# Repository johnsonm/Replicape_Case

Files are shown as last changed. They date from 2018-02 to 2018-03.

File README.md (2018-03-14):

Obsolete
========

This remix + design was abandoned and replaced by my from-scratch
(Replicase)[https://github.com/johnsonm/Replicase] design, done
entirely in OpenSCAD.  I have no intention to do any further work
on this remix of Replicape Case.  You are welcome to use it, but
I have no plans to pay attention to PRs for this repository.

OpenSCAD remixes of Replicape case, changing ventilation.

Originally:

https://www.thingiverse.com/thing:2610261
Replicape Case by andrewmirskytech is licensed under the Creative Commons - Attribution license.
http://creativecommons.org/licenses/by/3.0/

# Summary

A case for the Replicape with vents for two 30mm fans.

Use #4-40 x 3/4" countersunk (or M3 x 20) for top case.
Use #4-40 x 1/4" or M3 x 6mm for mounting the beaglebone.

There is now a bottom case version with mounting holes.

# How I Designed This

## OnShape

https://cad.onshape.com/documents/5606d2f84fb4a684de3a789f/w/2d6b5478c237fdbb73e455b0/e/285e4ce3e6625645cad0e7fc

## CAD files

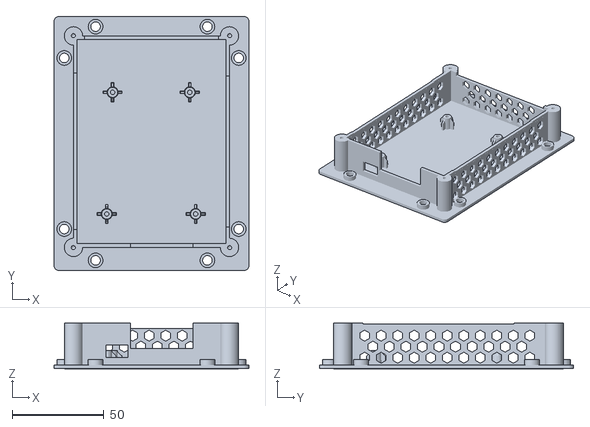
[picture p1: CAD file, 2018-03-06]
extra_ventilation_bottom_with_mounts.stl
106.1 x 138.4 x 24.8

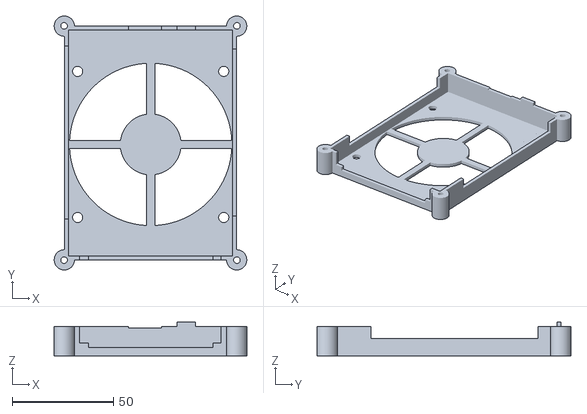
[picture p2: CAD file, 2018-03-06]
80mm-fan-top.stl
95.0 x 125.2 x 16.7

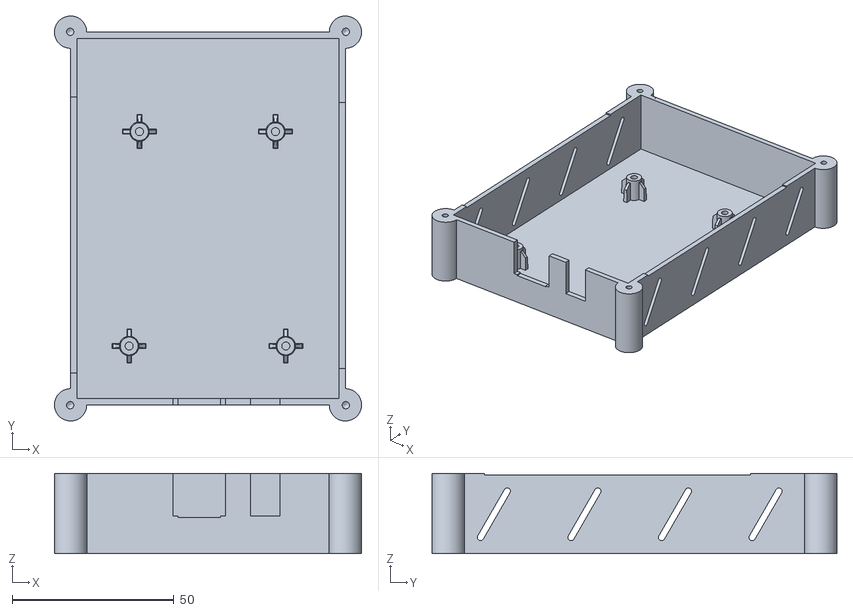
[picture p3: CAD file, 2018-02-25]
replicape_case_-_bottom.stl
95.0 x 125.2 x 24.8

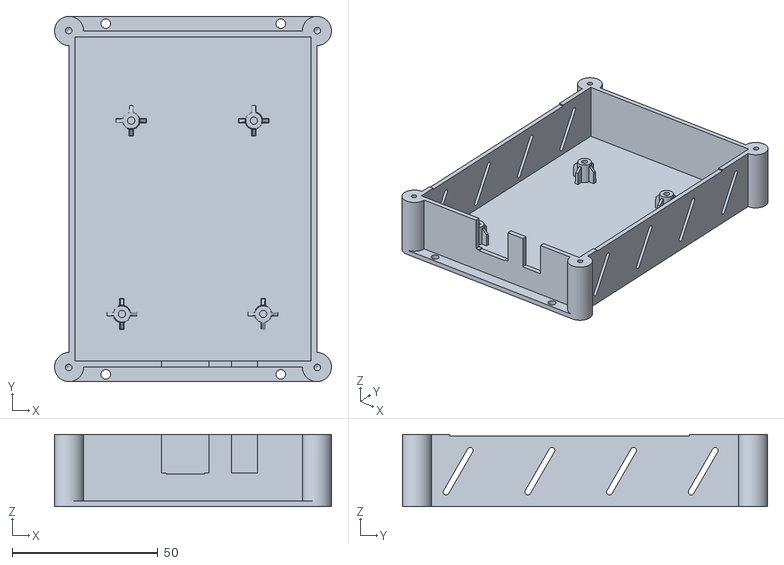
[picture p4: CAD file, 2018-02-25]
replicape_case_-_bottom_with_mounts.stl
95.0 x 125.2 x 24.8

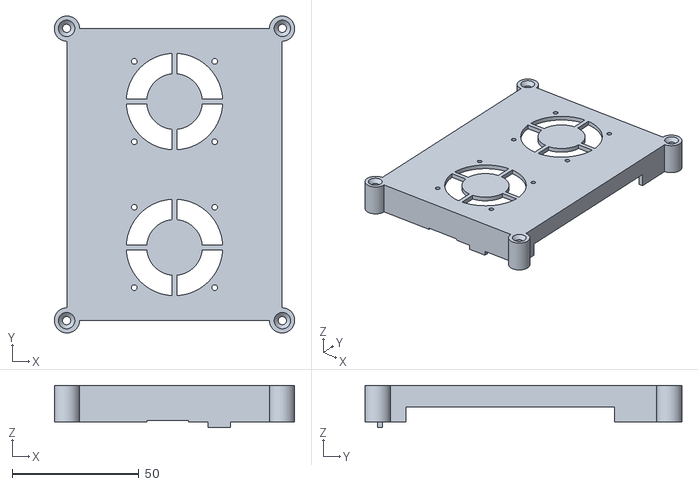
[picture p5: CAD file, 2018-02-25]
replicape_case_-_top.stl
95.0 x 125.2 x 16.6

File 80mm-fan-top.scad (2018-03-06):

// remove grills for two smaller fans
// replace with one 80mm fan
// this should be more parameterized; numbers are approximate
face = 2.02;
$fn = 180;
screw_off = 36; // x/y offsets for mounting screw holes
screw_d = 5;    // hole diameter for mounting screws

difference() {
    union() {
        // turn upside down and align with 0 Z to print and model
        translate([0, 0, 18.86]) rotate([180, 0, 0])
            import("replicape_case_-_top.stl");
        // fill in the old fan grills
        translate([-30, -50, 0]) cube([60, 100, face]);
    }
    union() {
        // this difference is itself subtracted, so the
        // effect is essentially inverted
        difference() {
            union() {
                // fan area
                cylinder(d=80, h=face);
                // mounting screw holes
                translate([-screw_off, -screw_off, 0]) cylinder(d=screw_d, h=face);
                translate([screw_off, -screw_off, 0]) cylinder(d=screw_d, h=face);
                translate([-screw_off, screw_off, 0]) cylinder(d=screw_d, h=face);
                translate([screw_off, screw_off, 0]) cylinder(d=screw_d, h=face);
            }
            union() {
                // grill center and bars
                cylinder(d=30, h=face);
                translate([-40, -2, 0]) cube([80, 4, face]);
                translate([-2, -40, 0]) cube([4, 80, face]);
            }
        }
    }
}

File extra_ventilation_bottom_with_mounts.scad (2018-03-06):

// I wanted a case with more airflow than the original design
// and with cutouts to fit the beaglebone green
// The case is not quite centered; the numbers are approximate
// There are a lot of "magic numbers" here from experimenting
x_off_p = 40.37;
x_off_n = 40.56;
shell = 2.05;
y_off_n = 58.31;
y_off_p = 54.88;
hd = 3; // air holes
m_d = 5.2; // diameter of mounting holes in flange
flange = 10; // width of mounting flange

module side_fill(x_off) {
    translate([x_off, -(y_off_n-(2*shell)), 0])
        cube([shell, 2*(y_off_n-(2*shell)), 23]);
}
module hex_hole(x, y, z, r=0) {
    $fn = 6;
    translate([x, y, z]) rotate([0, 90, r]) cylinder(r=hd, h=shell);
}
module vents(x_off) {
    for (y=[-(y_off_n-4*hd):3*hd:(y_off_n-4*hd)]) {
        hex_hole(x_off, y, 2*hd);
        hex_hole(x_off, y, 6*hd);
    }
    for (y=[-(y_off_n-5.5*hd):3*hd:(y_off_n-5.5*hd)]) {
        hex_hole(x_off, y, 4*hd);
    }
}
module end_vents(y_off) {
    for (x=[-(x_off_p-4*hd):3*hd:(x_off_n-4*hd)]) {
        hex_hole(x, y_off_p, 2*hd, 90);
        hex_hole(x, y_off_p, 6*hd, 90);
    }
    for (x=[-(x_off_p-5.5*hd):3*hd:(x_off_n-5.5*hd)]) {
        hex_hole(x, y_off_p, 4*hd, 90);
    }
}
module end_power_cutout() {
    translate([-(x_off_n-(2*shell)), y_off_p, 22])
        cube([x_off_p+x_off_n-(4*shell), shell, 3]);
}
module bbg_slots() {
    // beaglebone green has wider USB instead of 5V barrel,
    // and just leave room for some manufacturing variance
    translate([-11.5, -y_off_n, 11]) cube([34, shell, 15]);
    // and USB mini under the board
    translate([-25, -y_off_n, 6]) cube([12, shell, 7]);
}
module bottom_flange() {
    // designed to mount to corner of 2020 extrusion
    // similarly to original X5S electronics
    $fn = 30;
    y_n_fl = 2.4;
    mounting_holes = [
        // long sides
        [-(x_off_n+shell+flange/2), -(y_off_n-flange)],
        [-(x_off_n+shell+flange/2), y_off_p-flange],
        [x_off_p+shell+flange/2, -(y_off_n-flange)],
        [x_off_p+shell+flange/2, y_off_p-flange],
        // short sides
        [x_off_p-flange, y_off_p+shell+flange/2],
        [-(x_off_n-flange), y_off_p+shell+flange/2],
        [x_off_p-flange, -(y_off_n+shell+flange/2)],
        [-(x_off_n-flange), -(y_off_n+shell+flange/2)],
    ];
    difference() {
        union() {
            hull() {
                for (loc=[
                    [-(x_off_n+flange), -(y_off_n+flange)],
                    [x_off_p+flange, -(y_off_n+flange)],
                    [x_off_p+flange, y_off_p+flange],
                    [-(x_off_n+flange), y_off_p+flange],
                ]) {
                    x = loc[0];
                    y = loc[1];
                    translate([x, y, 0])
                        cylinder(d=m_d, h=shell);
                }
            }
            for (loc=mounting_holes) {
                x = loc[0];
                y = loc[1];
                translate([x, y, 0]) cylinder(d=8, h=5);
            }
        }
        union() {
            for (loc=mounting_holes) {
                x = loc[0];
                y = loc[1];
                translate([x, y, 0]) cylinder(d=m_d, h=5);
            }
        }
    }
}
difference() {
    union() {
        translate([0, 0, 20.4]) import("replicape_case_-_bottom.stl");
        side_fill(x_off_p);
        mirror([1,0,0]) side_fill(x_off_n);
        bottom_flange();
    }
    union() {
        vents(x_off_p);
        end_vents(y_off_p);
        mirror([1,0,0]) vents(x_off_n);
        bbg_slots();
        end_power_cutout();
    }
}

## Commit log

2018-02-25 First print
    [80mm-fan-top.scad, 80mm-fan-top.stl, replicape_case_-_bottom.stl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]
2018-02-26 Bottom case with extra ventilation
    [extra_ventilation_bottom_with_mounts.scad, extra_ventilation_bottom_with_mounts.stl]
2018-02-26 Comments in remixed top model; added missing text files
    [80mm-fan-top.scad]
2018-02-27 Adjustments from first print
    Change 80mm fan screw hole size and offset to fit; parameterize.
    Add/modify cutouts for BeagleBone Green connectors, add more
    parameters, add hex ventilation holes opposite connectors,
    reduce holes in long sides.
    [80mm-fan-top.scad, 80mm-fan-top.stl, extra_ventilation_bottom_with_mounts.scad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]
2018-03-05 Redesign mounting flanges to match Tronxy X5S 2020 corner mount
    [extra_ventilation_bottom_with_mounts.scad, extra_ventilation_bottom_with_mounts.stl]
2018-03-05 Remove interference with screw holes from side fill
    [extra_ventilation_bottom_with_mounts.scad, extra_ventilation_bottom_with_mounts.stl]
2018-03-06 Improvements from second test print
    On the lower section, cut out a notch to fit the power connectors on
    the replicape. Further clean out the ethernet/USB notch and widen
    it, since I had to cut out a little bit to fit the BBG into this print.
    Increase the size of the USB cutout slightly to be more likely to fit
    both the BBB mini-USB and BBG micro-USB in the same location. Make
    the bottom flange extend with holes on all four sides because the
    best mounting orientation is unclear. Add thickness to flange around
    mounting holes to accomodate mounting screws.
    On the upper section, make another attempt to get the screw hole locations
    correct for the 80mm fan. Reduce size of center face; proba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
    [80mm-fan-top.scad, 80mm-fan-top.stl, extra_ventilation_bottom_with_mounts.scad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]
